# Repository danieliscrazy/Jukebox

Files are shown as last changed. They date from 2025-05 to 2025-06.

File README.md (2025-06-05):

# Jukebox
This is an IRL Minecraft jukebox that plays 3D printed discs, powered by a Raspberry Pi Zero 2, an RC522 RFID board, and some really crappy Python code. This project is being made for and funded by Hack Club's Highway program.

Jukebox

| Item | Use | Source | Price | Total Price |
| ---- | --- | --- | ----- | --- |
| Raspberry Pi Zero 2 W | Brains of the system | Micro Center (in person) | $19.59 | |
| Inland 1.75mm PLA 3D Printer Filament - Black | To print out the case and discs | Micro Center (in person) | $19.59 | |
| Adafruit I2S 3W Class D Amplifier Breakout - MAX98357A | Speaker output for the Pi Zero | Micro Center (in person) | $6.48 | |
| Adafruit 3" Speaker (4Ω - 3W) | Speaker itself (I had a speaker already, but it isn't directly compatible with the I2S board, I'd have to cut the wire and I'm not willing to damage it) | Micro Center (in person) | $3.22 | |
| RC522 RFID/NFC Board | Detects the discs | Already owned | $0.00 | |
| NFC Stickers | Goes in the discs | Already owned | $0.00 | |
| Wires | ...they're wires. | Already owned | $0.00 | |
| | | | | $48.89 |

|  |  |  |
| --- | --- | --- |



> Disclaimer: Artificial intelligence was used in the making of this project's code. As such, that code is exempt from the GNU GPL v3 license the rest of the project is under. See [jukebox.py](jukebox.py) for more information.

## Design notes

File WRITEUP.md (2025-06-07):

# Jukebox

This is my Minecraft jukebox IRL project I made for Hack Club's Highway program! It uses a Raspberry Pi Zero 2 with an NFC shield to detect when discs are put in, and plays them out of the speaker in the back! I'm gonna go a bit more in depth about it here.

### Hardware
> I link to parts that I know are from reputable sources. Things I already have/don't remember where I got them from, I didn't link as I don't want to vouch for something I haven't purchased, and if you want to make this project you'll have to look for it yourself. Sorry!

The brains of this project is a [Raspberry Pi Zero 2 W](https://www.adafruit.com/product/5291). I was originally going to use a Pi 3 B+, as it has AUX output and the Zero 2 does not, but that ended up being too expensive for my grant, so I went with a Pi Zero 2 plus an [I2S amp](https://www.adafruit.com/product/3006) and a [3" speaker (4Ω 3W)](https://www.adafruit.com/product/1314). Requires a bit more configuring (see [here](https://learn.adafruit.com/adafruit-max98357-i2s-class-d-mono-amp/overview) for a tutorial), but works just fine. I used an RC522 board alongside a few 1" NFC tag stickers (NTAG215 tags, but it shouldn't matter really). I followed [this guide](https://pimylifeup.com/raspberry-pi-rfid-rc522/) by Pi My Life Up for the wiring and the Python setup. I used the script in their [GitHub README](https://github.com/pimylifeup/MFRC522-python/blob/master/README.md) as a test script.

jukebox wiring
> The wiring diagram for my project.

### Software

The [Python script I have](jukebox.py) is clunky, probably not efficient, and partially AI generated, but it gets the job done. For every song/disc/NFC tag, I just repeat the code. These are the songs themselves.

```

otherside = vlc.MediaPlayer("file:///home/danield/jukebox/otherside.mp3")
pigstep = vlc.MediaPlayer("file:///home/danield/jukebox/pigstep.mp3")
```

Each song has its own tag, and thus tag ID. To add a new disc, I just add an MP3 as shown above, add an `elif`, copy the code over, and replace the tag ID and the song. Simple when there's only 2 songs, but I plan to have 13 of them at least, so it'll get complicated fast. Like I said, clunky and inefficient, but it works!

```
try:
    while True:
        print("Hold a tag near the reader")
        id, text = reader.read_no_block()
        if id == 584186575628:
            if last_id != id:
                print("Detected! Playing!")
                otherside.play()
            last_id = id
            tries = 0
        elif id == 584196735387:
            if last_id != id:
                print("Detected! Playing!")
                pigstep.play()
            last_id = id
            tries = 0
```

It reads every .2 seconds to see if the disc is there. Then I have every song stop playing when the tags are removed. I also added some code to not immediately stop it unless it's been detected as gone 5 times, because it turns out the wall of the slot in the case is just barely too thick.

```
        else:
            if last_id is not None:
                tries += 1
                if tries >= 5:
                    print("No longer detected! Stopped!")
                    otherside.stop()
                    pigstep.stop()
                    last_id = None
                    tries = 0
        sleep(0.2)
```

Make sure you're in a venv (look at the Pi My Life Up guide above), and then install the packages:

```
pip3 install python-vlc mfrc522
```

I do feel the need to note that after completing this project, I found that [someone else already made a similar project](https://www.reddit.com/r/Minecraft/comments/12510sh/i_3dprinted_a_working_minecraft_jukebox_with_all/)! They used a software called [PhonieBox](https://phoniebox.de/index-en.html) which does basically all this does and more. I haven't tried it out so I can't vouch for it, but if you want to make this project, it might work better for you.

### Case

I made the case in TinkerCAD. While it isn't great for complex stuff, it _is_ great for simple geometric shapes, and you can't get more geometric than Minecraft blocks. Each pixel is an 8\*8\*8 mm cube, and each face is a millimeter lower than the frame and the pattern. 


> A face of the Jukebox broken down into pixels.

I ended up breaking it into 4 parts, the main body (4 of the 6 faces), the side panel (which has the hole for the speaker and for the Pi's power cable), the top panel (with the hole for the disc to go in), and the actual slot that holds the disc. The body and panels fit together in a sort of jigsaw way.


> All 4 pieces of the case.

I printed them on my Ender 3 V2 with PrusaSlicer at 15% infill and 0.28 mm layer height (except for the main body, which I printed at 0.2 mm to make sure it was _exactly_ 128 mm, this is likely unneccesary). I printed the top panel flat on the bed, and I printed the side panel upright to make sure the texture of the pattern didn't look weird once it was all together. Despite Prusa insisting on it, supports are not needed for a 1 mm overhang, and if there were supports there, they'd be impossible to remove. Because of that, I unfortunately had to disable auto supports and manually paint them on in the places they were actually needed, which was a pain in the butt.

I printed out all the pieces before I realized that they didn't fit together right, and I hadn't included tolerances into the design. I added tolerances of 0.2 mm to the top panel, side panel, and slot, and it fit together properly with the original body piece. 


> The pre-paint jukebox!

After that I just had to paint it! I used acrylic paint, which was a pain because I'm not good at painting. Spray paint would've been better, but acrylic worked. 

e6d2d8f9-c0e4-4e8b-b50d-6ad5c24ad641
> The finished product!

So yeah, that's how I made the jukebox!

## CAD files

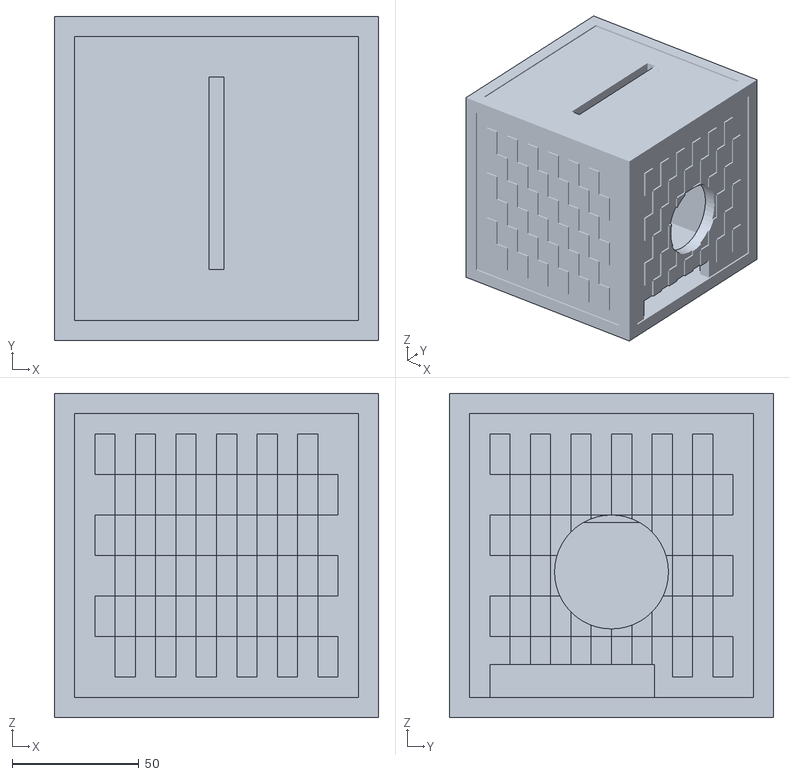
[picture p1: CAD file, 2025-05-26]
cad/jukebox_assembled.stl
128.0 x 128.0 x 128.0

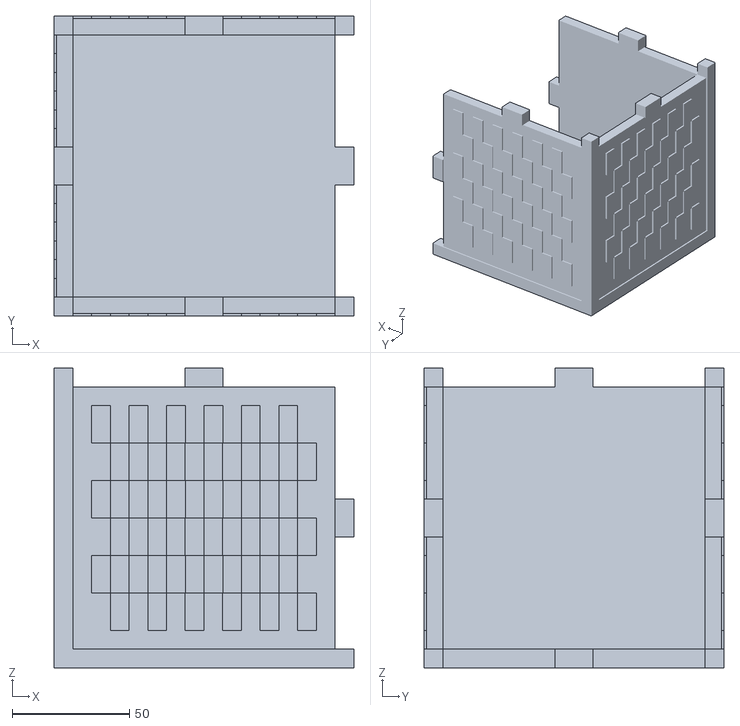
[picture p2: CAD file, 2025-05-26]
cad/jukebox_main.stl
128.0 x 128.0 x 128.0

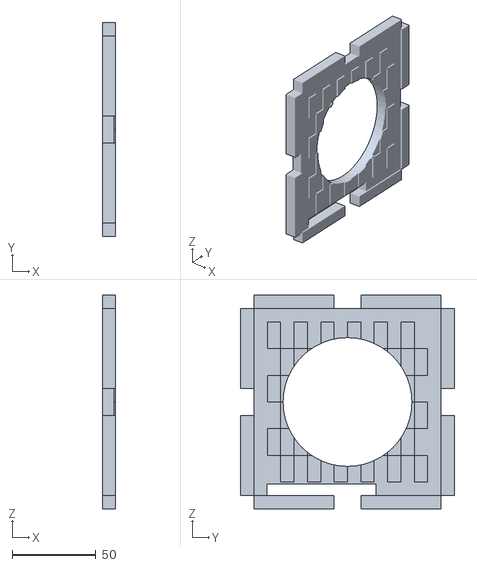
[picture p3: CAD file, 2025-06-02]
cad/jukebox_side_withtolerance.stl
8.00 x 128.0 x 128.0

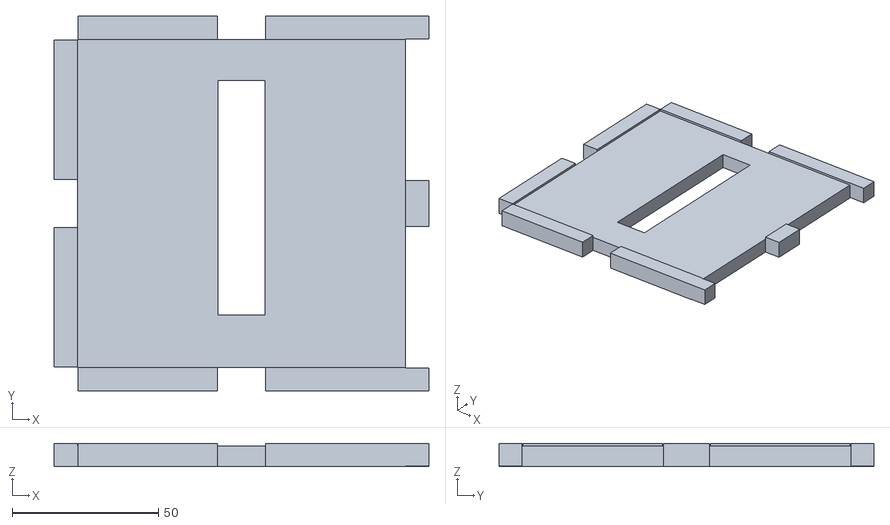
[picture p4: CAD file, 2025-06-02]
cad/jukebox_top_withtolerance.stl
128.0 x 128.0 x 8.00

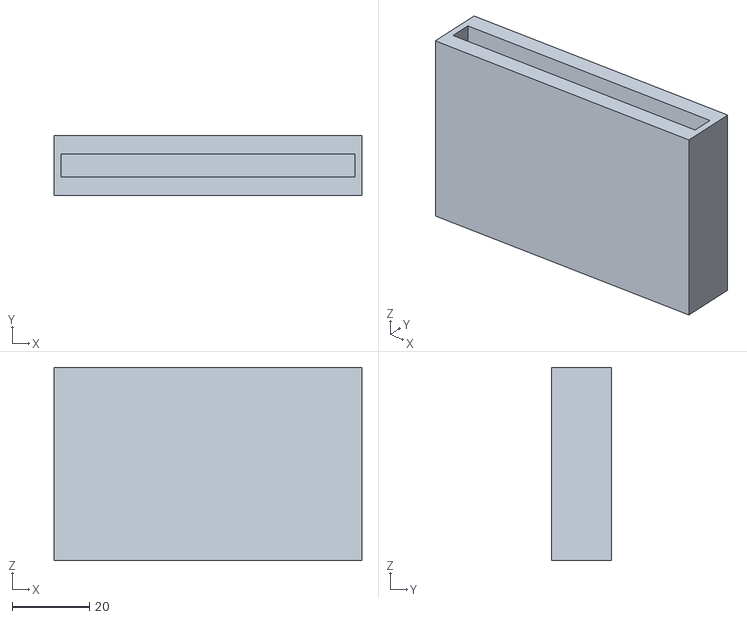
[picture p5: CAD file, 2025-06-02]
cad/jukebox_slot_withtolerance.stl
79.6 x 15.6 x 50.0

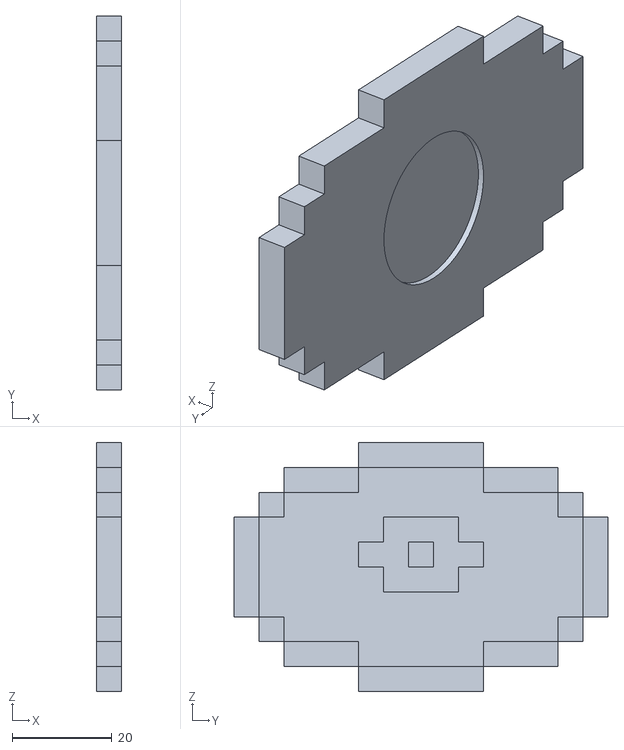
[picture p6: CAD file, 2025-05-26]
cad/jukebox_disc.stl
5.00 x 75.0 x 50.0

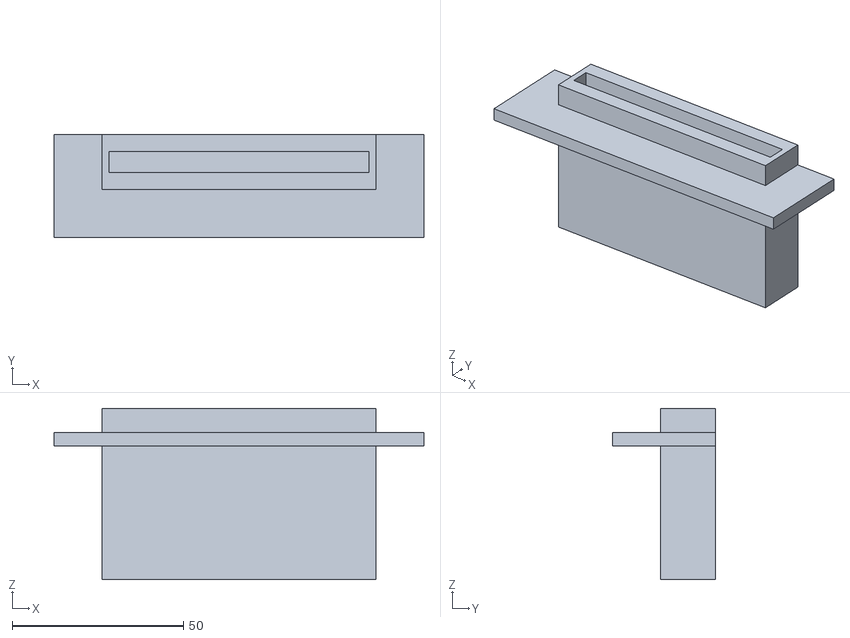
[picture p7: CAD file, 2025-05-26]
cad/jukebox_slot.stl
108.0 x 30.0 x 50.0

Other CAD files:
cad/jukebox_side.stl
cad/jukebox_top.stl

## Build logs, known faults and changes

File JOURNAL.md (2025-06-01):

---
title: "Jukebox"
author: "@dld"
description: "Physical Minecraft Jukebox that plays discs!"
created_at: "2025-05-22"
---
> I spent approximately 7 hours on this so far.

This is the start of my journal file! This project is a physical Minecraft jukebox that plays physical discs! This will be accomplished using a 3d printed model with a Pi Zero W powering it, an RC522 RFID shield, a wired speaker (maybe Bluetooth if I can't get OTG working), and RFID chips I put into the discs (hardware choices are not final). Everything will be 3D printed. I'd add more but I need to go to my next class, so I'll add more later.

### May 23, 2025
Going to start doing work and research on this stuff. Time is 1:17 PM for my own future reference. I know this might be bad practice but I'm just gonna make a commit every time I edit the journal. Anyways, I think that I might instead of a Pi Zero use a 3 B+, because the Zero has no native wired output, and getting it and a HAT would be about the same cost as getting a Pi 3 B+. Gonna look at how I could do the NFC interface and code now.

1:32 PM: Using [this](https://www.instructables.com/RFID-RC522-Raspberry-Pi/) for reference for wiring and maybe the basis of the RC522 interface. My dumb ass just remembered I need to actually flash Pi OS onto my Pi. I'm gonna do that first lol.

2:00 PM: Finally put my Hack Club SD card to good use! Trying to wire up and test out the RFID board now.

2:10 PM: Nevermind, that tutorial uses Python 2 (despite being from only 2017). Gonna try [this one](https://pimylifeup.com/raspberry-pi-rfid-rc522/) instead.

2:53 PM: Had to take a roughly 45 minute break. Didn't get to wiring up anything yet, will do it now!

3:09 PM: Wired up and basic tests are working! Going to take a break for now (even though I've only gotten a bit done). Not sure how much of the time I've spent was just me slacking off but I'd say between getting it set up and the bit of research I did before starting this journal entry I've done about an hour of work.

IMG_3839 (1)
> My crappy photo of my setup, scanning a Dave and Busters card (yes ik my floor's dirty)


> The terminal output on my Pi

### May 24, 2025
10:24 AM: I'm gonna work on the 3D models now. Gonna make them in TinkerCAD as that's what I'm most experienced with. I think for size I'm basically going to do each pixel is 8 mm (so the whole jukebox will be a 128 mm cube).

10:50 AM: Got one face of the jukebox done. I'm gonna need to make the discs at a weird scale so that they fit, they'll be around 5mm pixels. Taking a break now and will log again right when I come back.


> A side of a jukebox!
 
12:06 PM: Back! Getting back to work.

12:26 PM: Finished the basic structure. Gonna try to work on how the electronics fit in now.


> A jukebox!

12:59 PM: Got the basic structure of how it's gonna work down. Basically now all I need is to put in space for the Raspberry Pi (and the speaker, which I'm just now realizing I've done no work on researching) and divy it up so it can be printed. I made a GIF!


> How the discs will work. The circle in the disc is for the NFC tags.

1:45 PM: Just remembered I got my current Pi 3 B+ from a Kano kit, which had a speaker case in it. I think I can easily adapt it to fit this. With that, I think my case is nearing completion, just need to figure out how I'll assemble it. Also, I found out that someone else online made something like this before! They used a software called [PhonieBox](https://phoniebox.de/index-en.html), which seems to be exactly what I need, but I do want to try to make this myself because I feel like that wouldn't be in the spirit of Highway. If I can't get it to work in Python though, I will use that.


> The jukebox with a speaker hole and a hole for the Raspberry Pi's ports.

2:43 PM: Haven't worked any more since 2. Gonna work more now.

3:13 PM: Split it up into 6 pieces, but currently can't figure out how to connect them. Was going to just use pegs but that didn't really work, because in order to take it apart the way I wanted, I'd need to put supports in the holes, which would be impossible to remove. Stopping for today. Believe I've worked around 3 hours (bringing the total to 4).

7:30 PM: Been working on this a bit more for like 30 minutes, I think I'm gonna try using this sort of jigsaw style way to join it, making it altogether 4 pieces printed out, the bottom and 3 sides as one piece, the side with the speaker and the Pi as another, the top piece as one, and then the slot for the disc. Gonna try making a test print of the case to see if it all works together.


> The back of the jukebox, with the new joining method


> All of the parts laid out

### May 25, 2025

9:15 AM: Test print failed, filament got tangled, need to run it again but honestly I've been too lazy to relevel the printer (I really need to get a BLTouch), I'll get around to it. Been working on the software aspect of it for about half an hour now. Not great at Python so basically just cobbling bits and pieces of code that come up when I Google search "rc522 python" and "python playing music". Gonna make the first commit in a few with some test code so that I can just grab the code from GitHub instead of messing with SCP.

10:20 AM: After some issues with the speaker, I got the base code to work, it plays a song when 1 of the tags. Now what I need to do is to implement multiple discs, and figure out how to detect when it's been removed. I'm rather stumped on that last part. I might need to use Copilot for help. If I do, I'll make it blatantly clear what sections are helped by AI. I've been working for about an hour and 15 minutes so far today, today, bringing the toal to like 5 hours and 45 minutes I've worked on this.

10:33 AM: I did end up using Copilot, and I added a disclaimer to my code file, but it seems to work now! I just need to make a bunch of different tags and make it work for multiple of them. Signing off for now, got some school work I need to get done, and I think that brings me up to about a nice even 6 hours. Once I get the code finished, I'll finalize the 3D files, upload them, and get ready to submit it!

### May 26, 2025

12:18 PM: I've been working for I'd say 45 minutes on this, mostly the code but also some wiring (damn thing keeps coming loose). My code is janky and doesn't have all the songs yet, but it works! I think I'm ready to submit. Gonna upload all the STL files and all that.

### May 28, 2025

1:00 PM: Pi 3 wasn't approved, but Alex did point me in the right direction with a Pi Zero and an I2S board. Gonna update the case and BOM, and then I should hopefully be good to go!

1:18 PM: TinkerCAD on a 2012 MacBook *sucks*. I got the case fixed anyways. Had to put a new, bigger speaker in since otherwise I'd have to splice open my current speaker, but it's only 3 bucks.


> New side panel!

### May 30, 2025

4:45 PM: Got all my parts from Micro Center! Loaded up the filament and running the side panel print. Had to add .2mm tolerances because the test parts didn't fit together, will upload corrected CAD files in a few. Got the speaker and I2S board soldered up, gonna try to set up the code on my existing Pi 3 first before moving over to the Pi Zero, because I don't have a mini HDMI cable or a USB OTG adapter. It's now closer to 6:00 and I still haven't made this commit. Woops! Drowsy because I might've taken 2 doses of a medicine (I'm all good just tired now), so can't work on electronics today. Maybe tomorrow or Sunday afternoon. Bye!

### June 1, 2025

11:45 AM: Yesterday, I got it all assembled! I still need to paint it and print out more discs, but it works! [Here's a test video of it!](https://imgur.com/sRMTtmy) I've kinda given up on tracking time at this point, I'd say I probably worked around 3 or so more hours at least on getting this all put together.

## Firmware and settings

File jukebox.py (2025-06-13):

# This code was partially made with the use of Copilot AI, specifically the functionality for detecting the removal of the NFC tag.
# Given that most of the non-AI code was cobbled together from posts on Reddit, StackOverflow, and the Raspberry Pi forum, this code is exempted from the GNU GPLv3 that the rest of the repository is under. I take no credit or ownership of its contents, and you are free to do whatever you want with it.

from time import sleep
import sys
import RPi.GPIO as GPIO
from mfrc522 import SimpleMFRC522
import vlc
reader = SimpleMFRC522()

chirp = vlc.MediaPlayer("file:///home/danield/jukebox/chirp.mp3")
otherside = vlc.MediaPlayer("file:///home/danield/jukebox/otherside.mp3")
mellohi = vlc.MediaPlayer("file:///home/danield/jukebox/mellohi.mp3") 
cat = vlc.MediaPlayer("file:///home/danield/jukebox/cat.mp3") 
ward = vlc.MediaPlayer("file:///home/danield/jukebox/ward.mp3")
blocks = vlc.MediaPlayer("file:///home/danield/jukebox/blocks.mp3")
mall = vlc.MediaPlayer("file:///home/danield/jukebox/mall.mp3")
eleven = vlc.MediaPlayer("file:///home/danield/jukebox/eleven.mp3")
far = vlc.MediaPlayer("file:///home/danield/jukebox/far.mp3")
thirteen = vlc.MediaPlayer("file:///home/danield/jukebox/thirteen.mp3")
stal = vlc.MediaPlayer("file:///home/danield/jukebox/stal.mp3")
strad = vlc.MediaPlayer("file:///home/danield/jukebox/strad.mp3")
waiit = vlc.MediaPlayer("file:///home/danield/jukebox/wait.mp3") # not sure if "wait" can be a constant in python so just naming it "waiit"

start = vlc.MediaPlayer("file:///home/danield/jukebox/start.mp3")

last_id = None

tries = 0
start.play()
try:
    while True:
        print("Hold a tag near the reader")
        id, text = reader.read_no_block()
        if id == 584186575628:
            if last_id != id:
                print("Detected Otherside! Playing!")
                otherside.play()
            last_id = id
            tries = 0
        elif id == 584187564821:
            if last_id != id:
                print("Detected Chirp! Playing!")
                chirp.play()
            last_id = id
            tries = 0
        elif id == 584197590179:
            if last_id != id:
                print("Detected Mellohi! Playing!")
                mellohi.play()
            last_id = id
            tries = 0
        elif id == 584189789991:
            if last_id != id:
                print("Detected Cat! Playing!")
                cat.play()
            last_id = id
            tries = 0
        elif id == 584191236310:
            if last_id != id:
                print("Detected Ward! Playing!")
                ward.play()
            last_id = id
            tries = 0
        elif id == 584190455573:
            if last_id != id:
                print("Detected Blocks! Playing!")
                blocks.play()
            last_id = id
            tries = 0
        elif id == 584195369639:
            if last_id != id:
                print("Detected Mall! Playing!")
                mall.play()
            last_id = id
            tries = 0
        elif id == 584197471632:
            if last_id != id:
                print("Detected 11! Playing!")
                eleven.play()
            last_id = id
            tries = 0
        elif id == 584184558949:
            if last_id != id:
                print("Detected Far! Playing!")
                far.play()
            last_id = id
            tries = 0
        elif id == 584192489952:
            if last_id != id:
                print("Detected 13! Playing!")
                thirteen.play()
            last_id = id
            tries = 0
        elif id == 584195431570:
            if last_id != id:
                print("Detected Stal! Playing!")
                stal.play()
            last_id = id
            tries = 0
        elif id == 584188748081:
            if last_id != id:
                print("Detected Strad! Playing!")
                strad.play()
            last_id = id
            tries = 0
        elif id == 584184358515:
            if last_id != id:
                print("Detected Wait! Playing!")
                waiit.play()
            last_id = id
            tries = 0
        else:
            if last_id is not None:
                tries += 1
                if tries >= 2:
                    print("No longer detected! Stopped!")
                    otherside.stop()
                    chirp.stop()
                    mellohi.stop()
                    cat.stop()
                    ward.stop()
                    blocks.stop()
                    mall.stop()
                    eleven.stop()
                    far.stop()
                    thirteen.stop()
                    stal.stop()
                    strad.stop()
                    waiit.stop()
                    last_id = None
                    tries = 0
        sleep(0.2)

except KeyboardInterrupt:
    GPIO.cleanup()

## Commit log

2025-05-26 Added CAD files
    [jukebox_assembled.stl, jukebox_disc.stl, jukebox_main.stl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]
2025-05-28 Updated the side panel
    [jukebox_side.stl]
2025-06-01 Added delayed removal so it doesn't glich
    [jukebox.py]
2025-06-02 Added files with tolerance
    [jukebox_side_withtolerance.stl, jukebox_slot_withtolerance.stl, jukebox_top_withtolerance.stl]
